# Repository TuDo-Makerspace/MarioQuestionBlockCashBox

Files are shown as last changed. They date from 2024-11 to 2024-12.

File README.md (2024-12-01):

# Mario [ ? ] Block Cash Box <!-- omit in toc -->

https://github.com/user-attachments/assets/13c91ebd-0a8e-42fc-bb54-711a1d9b547c

## Table of Contents <!-- omit in toc -->

- [Building the Box](#building-the-box)
  - [Step 1. Cut the Wood](#step-1-cut-the-wood)
  - [Step 2. Glue the Pieces Together](#step-2-glue-the-pieces-together)
  - [Step 3. Secure the Bottom](#step-3-secure-the-bottom)
  - [Step 4. Lid slit](#step-4-lid-slit)
  - [Step 5. Hole for DC Jack](#step-5-hole-for-dc-jack)
  - [Step 6. Paint the Base Coat](#step-6-paint-the-base-coat)
  - [Step 7. Draw the Pixel Grid](#step-7-draw-the-pixel-grid)
  - [Step 8. Paint the Pixel Art](#step-8-paint-the-pixel-art)
  - [Step 9. Magnets for the Lid](#step-9-magnets-for-the-lid)
- [Electronics](#electronics)
  - [Components Required](#components-required)
  - [Wiring the Components](#wiring-the-components)
- [Software](#software)
  - [Overview](#overview)
  - [Configurable Parameters](#configurable-parameters)
  - [Sound Playback Implementation](#sound-playback-implementation)
- [Flashing the Arduino](#flashing-the-arduino)
- [Electronics Enclosure](#electronics-enclosure)
  - [Enclosure Components](#enclosure-components)
  - [Assembly Instructions](#assembly-instructions)
    - [1. Mounting the Perfboard](#1-mounting-the-perfboard)
    - [2. Attaching Speaker and Sensor](#2-attaching-speaker-and-sensor)
    - [3. Connecting Components](#3-connecting-components)
    - [4. Securing the Enclosure](#4-securing-the-enclosure)
    - [5. Sensor Calibration](#5-sensor-calibration)
    - [6. Screwing on the Lid](#6-screwing-on-the-lid)

## Building the Box

### Step 1. Cut the Wood

For the box, we cut 2 slightly larger pieces (dimensions: X x Y x Z) and 4 slightly smaller pieces (dimensions: X x Y x Z). The larger pieces make up the top and bottom, while the smaller pieces form the sides.

<div align="center">
  Cutting Wood
</div>

### Step 2. Glue the Pieces Together

Once the pieces are cut, glue them together to form the box. Make sure the edges are flush and the corners are square.

<div align="center">
  Gluing
</div>

### Step 3. Secure the Bottom

Attach the bottom of the box using screws or nails for extra stability. Glue alone can work but might not be as durable.

<div align="center">
  Screwing the Bottom
</div>

### Step 4. Lid slit

Cut a slit in the lid to allow coins to be inserted into the box. Make sure the slit is wide enough to accommodate different coin sizes.
We used a size of X x Y.

TODO: Add Image

### Step 5. Hole for DC Jack

Drill a hole into the bottom of any side of the box to make room for a DC jack. We didn't have a panel mount DC jack, so we used a PCB one and simply glued it into the hole. We also soldered a JST connector to the jack so that it can be easily connected to the electronics, while still allowing the other electronics to be removed from the box for maintenance.

### Step 6. Paint the Base Coat

Apply a white base layer of paint to the box. This will make the final colors more vibrant. Acrylic paint is recommended.

<div align="center">
  Base Paint
</div>

### Step 7. Draw the Pixel Grid

Sketch a 16x16 pixel grid on the box. This will serve as a guide for your Super Mario-inspired design.

<div align="center">
  Pixel Grid
</div>

### Step 8. Paint the Pixel Art

Fill in the grid with bright colors to create the iconic Mario Question Block design.

<div align="center">
  Painting Pixels
</div>

### Step 9. Magnets for the Lid

Drill a hole into each corner of the box and lid. Insert and glue magnets into the holes. This allows the lid to remain in place, while still being easy to open.

<div align="center">
  Finished Product
</div>

## Electronics

### Components Required

For the electronics setup, you'll need the following components:

- [Arduino Nano](https://www.amazon.de/s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)
- [PAM8403 Audio Amplifier Board](https://www.amazon.de/DollaTek-5V-Audioverst%C3%A4rker-Digitalendstufenmodul-Stereo-Verst%C3%A4rker-Potentiometer/dp/B07DJWGQVY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)
- [KY-033 Line Tracking Sensor](https://www.amazon.de/KY-033-Anwendbar-Erkennung-Hindernissen-Infrarot-Detektionssensor/dp/B0D3XHR2VL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)
- [Speaker (8- or 4-ohm, rated for 3W or higher)](https://www.amazon.de/s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)

### Wiring the Components

Connect the components as illustrated in the circuit diagram below:

> TODO: Add Circuit Diagram

Circuit Diagram

For our project, we soldered the components onto a perfboard:

> Tip: We utilized JST connectors for connecting the speaker, sensor, and power supply to the perfboard. This allows for better maintainability.

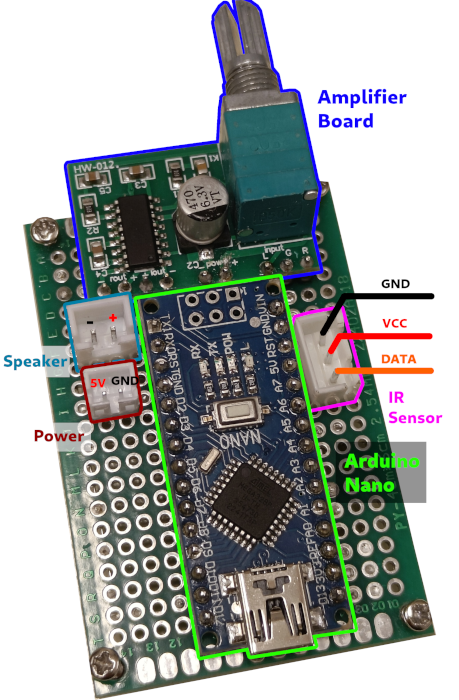
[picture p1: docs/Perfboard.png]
Perfboard


## Software

### Overview

The project's software can be found in the [`src/`](src/) directory. It performs the following actions:

1. Initialization:
   - Initializes GPIO's and serial communication.
   - Displays a playful ASCII art message in the serial monitor.

2. Sensor Monitoring:
   - Continuously monitors input from the KY-033 line tracking sensor.
   - Detects objects (e.g., coins) passing over the sensor by detecting a transition from LOW to HIGH on the sensor pin.

3. Sound Playback:
   Once a coin is detected:
   - Standard: Plays the classic Mario coin sound effect each time a coin is detected.
   - Special: On every *n-th* coin (configurable), it plays either a One-Up or Power-Up sound effect instead of the standard coin sound. Currently, the Power-Up sound is played on every 4th coin and the One-Up sound on every 10th coin.

### Configurable Parameters

At the top of the main file, you can adjust the following parameters:

- `POWER_UP`: Determines the number of coins required to play the Power-Up sound effect.
- `ONE_UP`: Determines the number of coins required to play the One-Up sound effect.
- `SENSOR_PIN`: Specifies the pin connected to the KY-033 sensor.
- `WAIT_AFTER_COIN`: Sets the waiting time between consecutive sound playbacks. This prevents spam if the coin is detected for a longer duration.

### Sound Playback Implementation

We utilize [Damellis's PCM Library](https://github.com/damellis/PCM) to handle audio playback. To play a sound, we can use the startPlayback() function, which takes an array of raw 8-bit audio values. The Mario audio samples are stored in the `sounds.h` file as byte arrays, however, due to copyright restrictions, `sounds.h` is not included in this repository. Makerspace Members can access the file on our file server. For others, refer to this [Tutorial](https://highlowtech.org/?p=1963) for instructions.

## Flashing the Arduino

To upload the software to your Arduino Nano, follow these steps:

1. Install PlatformIO:
   - Download and install [PlatformIO](https://platformio.org/) as an extension for your preferred IDE (e.g., VS Code).

2. Open the Project:
   - Launch PlatformIO and open this project by navigating to `File > Open Folder` and selecting the project's root directory.

3. Connect Your Arduino:
   - Use a USB cable to connect your Arduino Nano to your computer.

4. Upload the Firmware:
   - In PlatformIO, click the Upload button (usually represented by an arrow icon) to compile and flash the software to your Arduino.

## Electronics Enclosure

To securely house the electronics and ensure proper protection, we designed and 3D printed a custom enclosure tailored specifically to our components (i.e. our Speaker, Perfboard etc.). Provided that you likely have different components, you will need to come up with your own enclosure design. **This section mostly serves as a reference for members of our makerspace to repair or modify our coin box.**

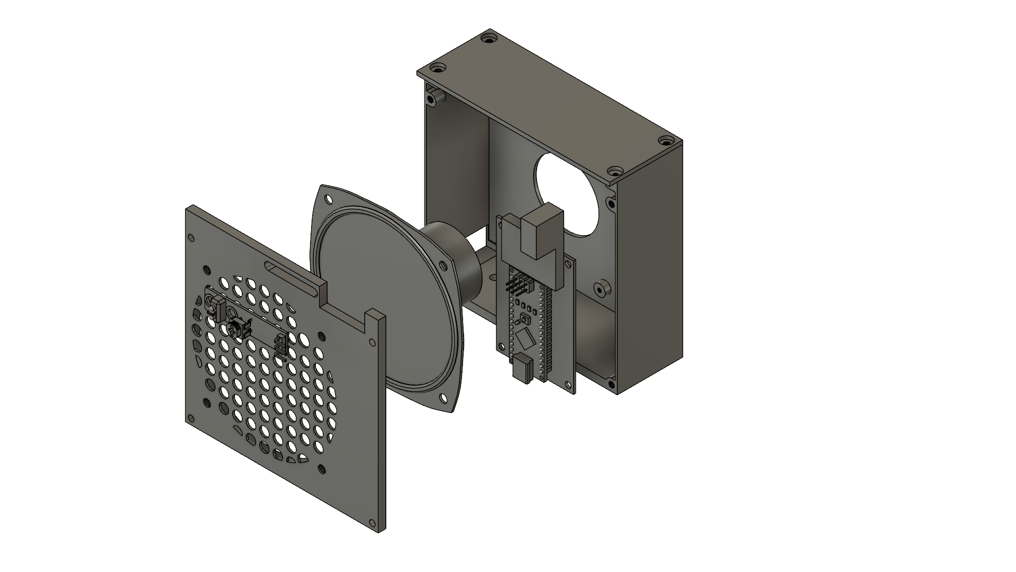
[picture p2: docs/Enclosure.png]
Enclosure


### Enclosure Components

The enclosure consists of three main parts. Click on the links below to download the corresponding `.3mf` files:

- [Back Part](enclosure/Back.3mf): Holds the perfboard containing the Arduino Nano and the Audio Amplifier.
- [Front Part](enclosure/Front.3mf): Houses the speaker and the sensor.
- [Lid](enclosure/Lid.3mf): Covers the enclosure once the front and back parts are assembled.

### Assembly Instructions

#### 1. Mounting the Perfboard

Secure the perfboard onto the Back Part of the enclosure using M2 screws.

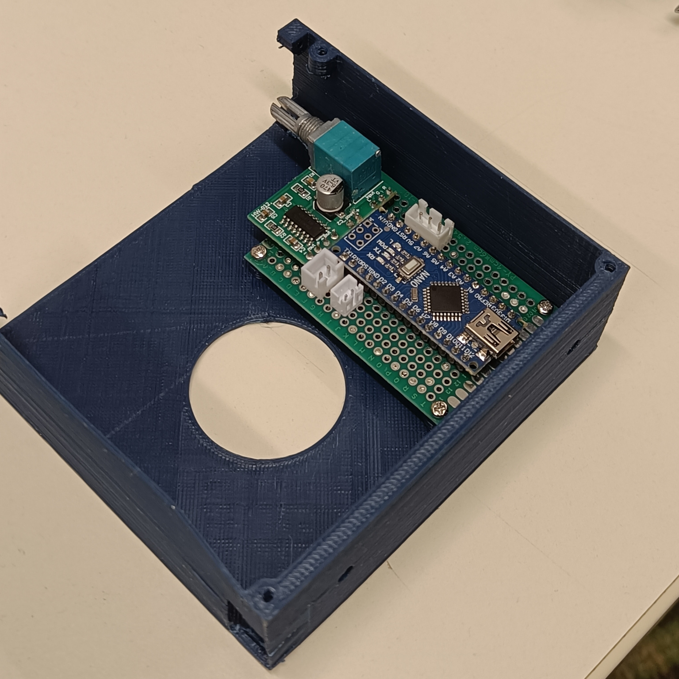
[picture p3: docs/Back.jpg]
Back Part
   

#### 2. Attaching Speaker and Sensor

Attach the speaker and KY-033 sensor to the Front Part of the enclosure using M3 screws and a nut.

> Note: Do not fully tighten the nut for the sensor yet, as you may need to adjust its position later.
   
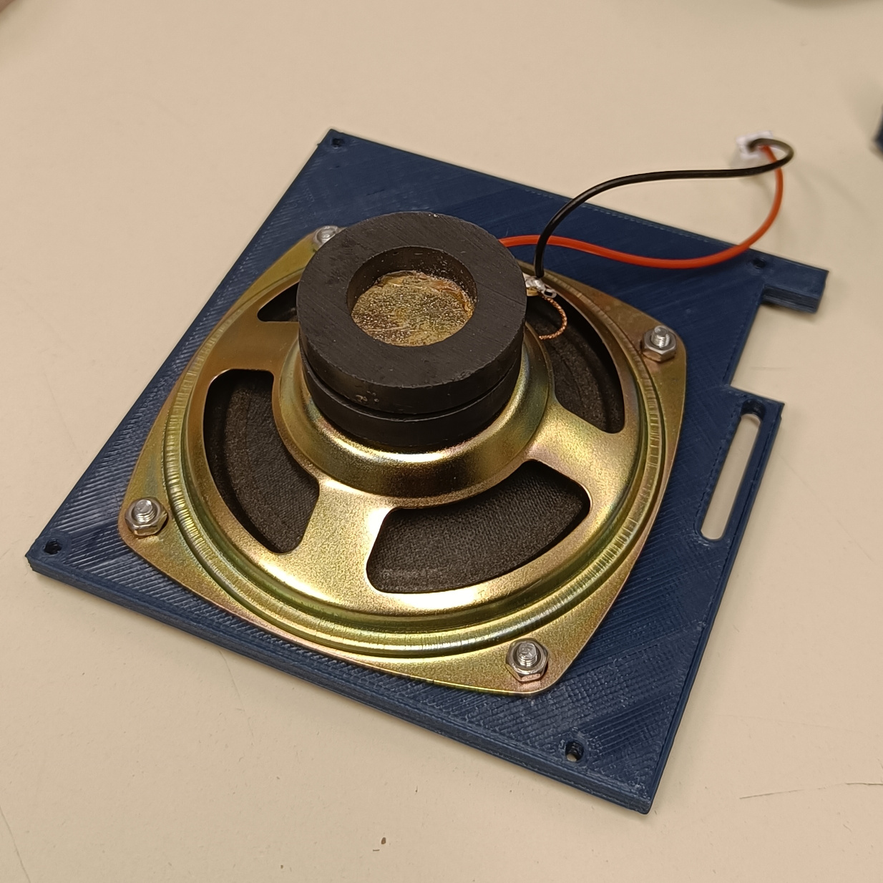
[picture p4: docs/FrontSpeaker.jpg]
Front Part
   
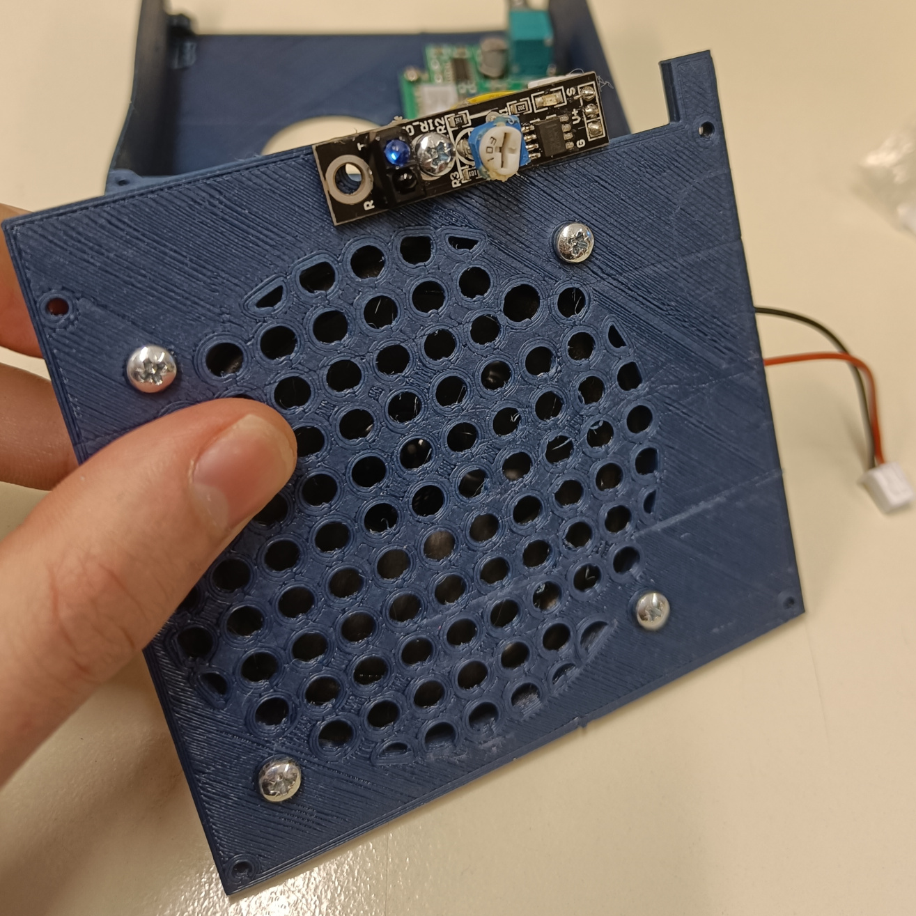
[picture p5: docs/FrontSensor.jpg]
Front Part
   

#### 3. Connecting Components

Connect the sensor, speaker, and DC barrel jack to the perfboard.

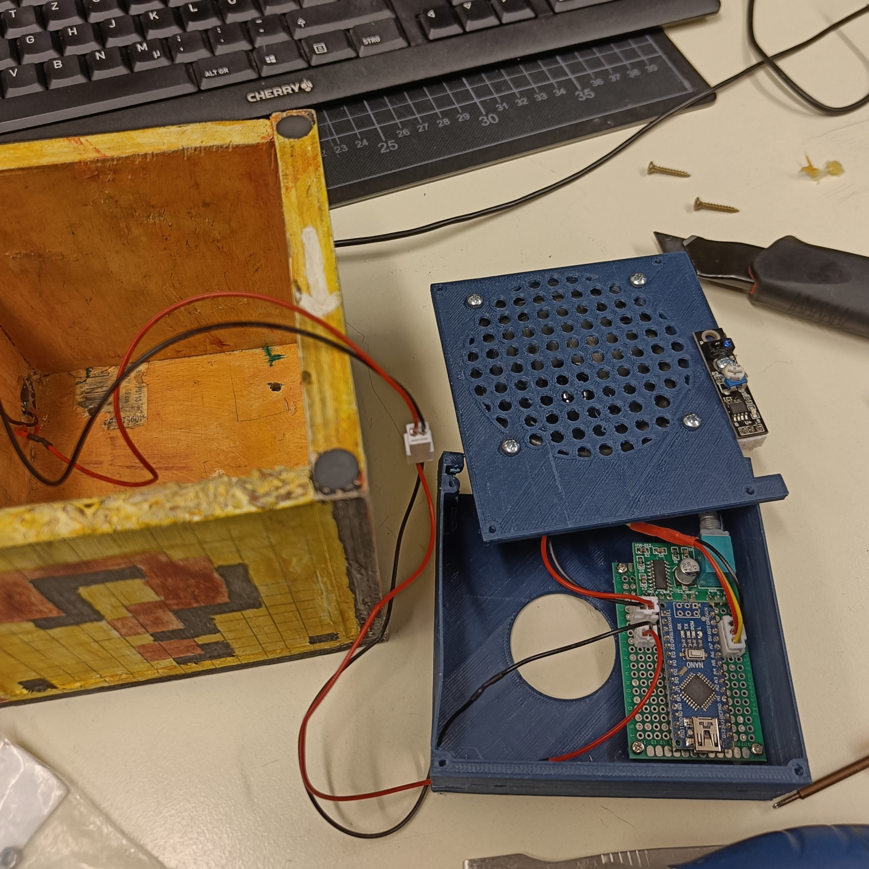
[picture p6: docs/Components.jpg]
Components


#### 4. Securing the Enclosure

Screw the front and back parts together using M3 screws. Then insert the assembled electronics into the wooden box. This may require some force. Use two wooden screws from the bottom of the wooden box to secure the enclosure in place through the designated holes.

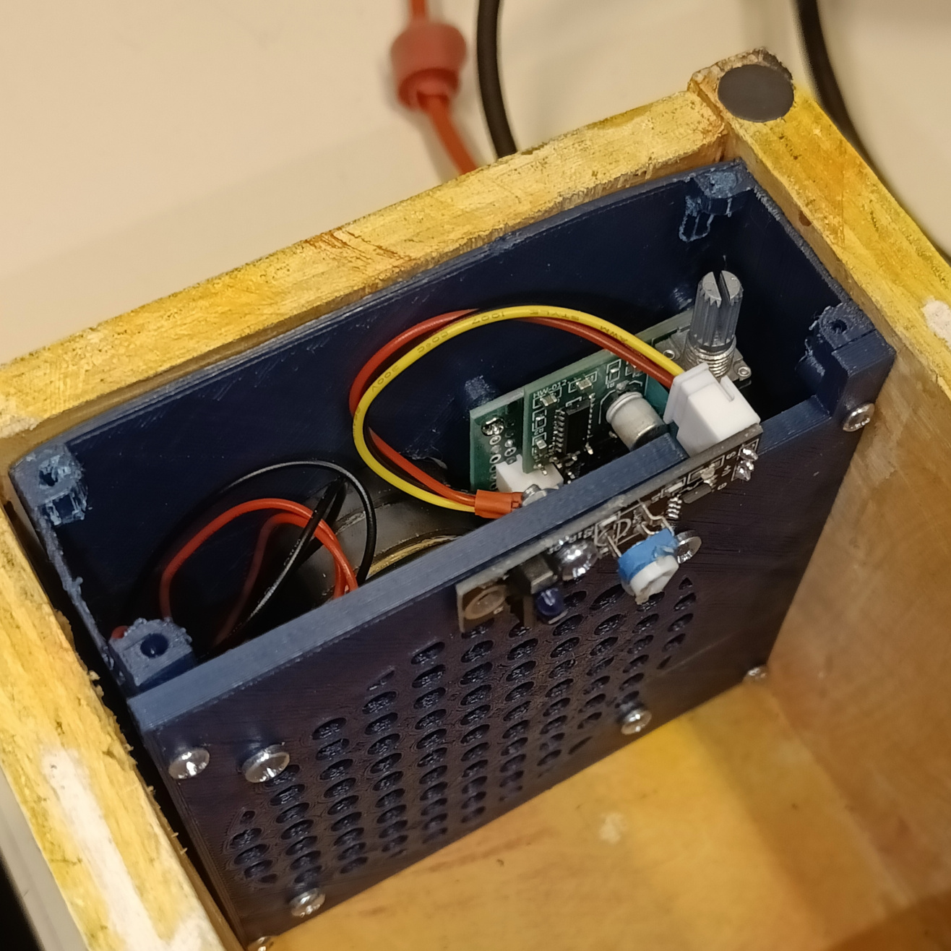
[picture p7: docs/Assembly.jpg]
Assembled

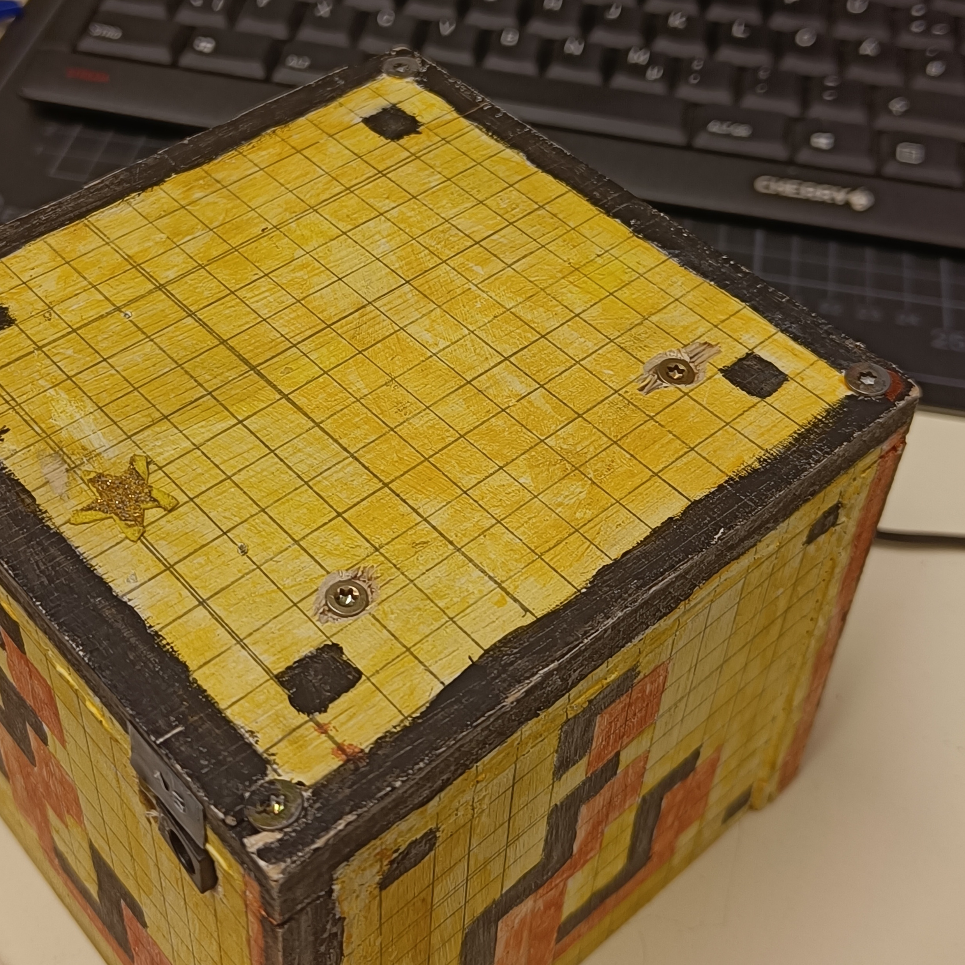
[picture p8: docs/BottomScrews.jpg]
Bottom Screws


#### 5. Sensor Calibration

- Before attaching the lid, power up the electronics and calibrate the sensor sensitivity to detect coins.
- Place the box lid on top of the enclosure.
- Test the sensor by inserting small coins. If the sensor misses any coins, adjust its position by loosening the nut, repositioning the sensor, and then tightening the nut once satisfied.

#### 6. Screwing on the Lid

Once the sensor is properly positioned, secure the 3D printed lid onto the enclosure using three M3 screws and one M2 screw.

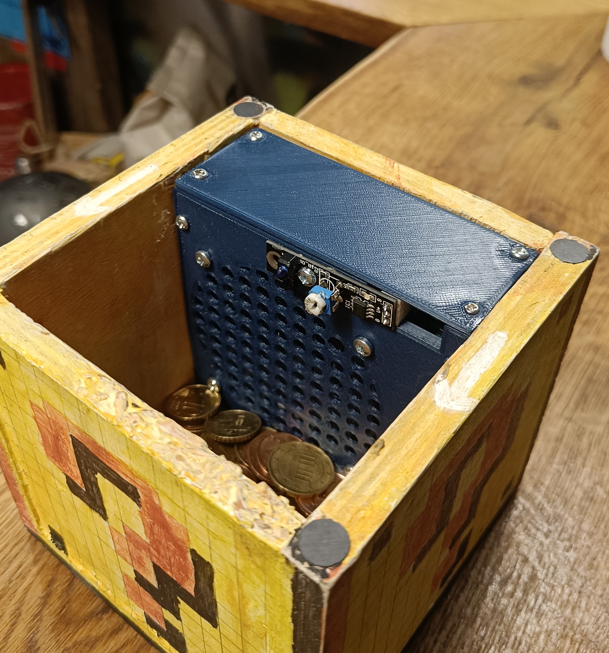
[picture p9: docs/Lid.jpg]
Lid


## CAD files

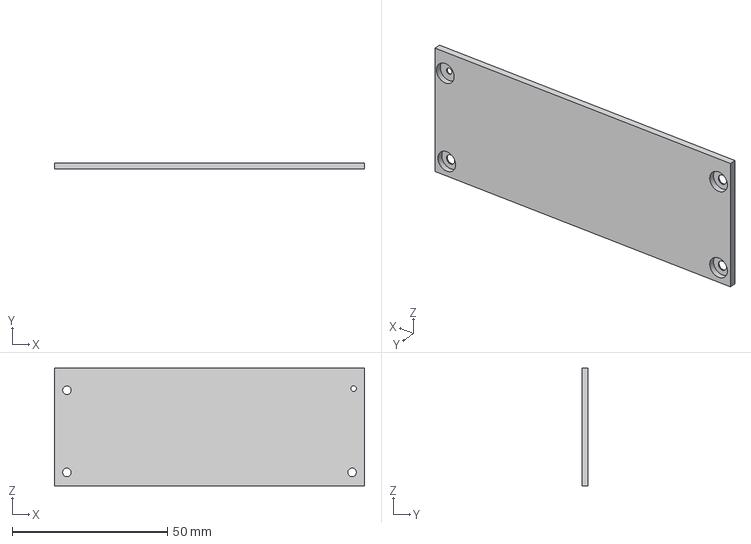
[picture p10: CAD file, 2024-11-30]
enclosure/Lid.3mf
100.0 x 2.00 x 38.0 mm

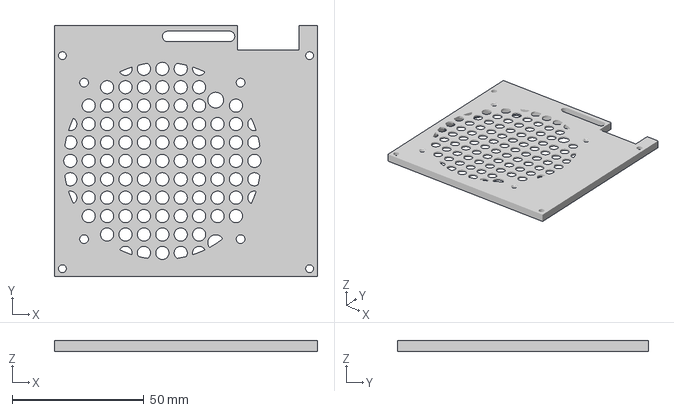
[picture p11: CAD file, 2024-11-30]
enclosure/Front.3mf
100.0 x 95.5 x 4.00 mm

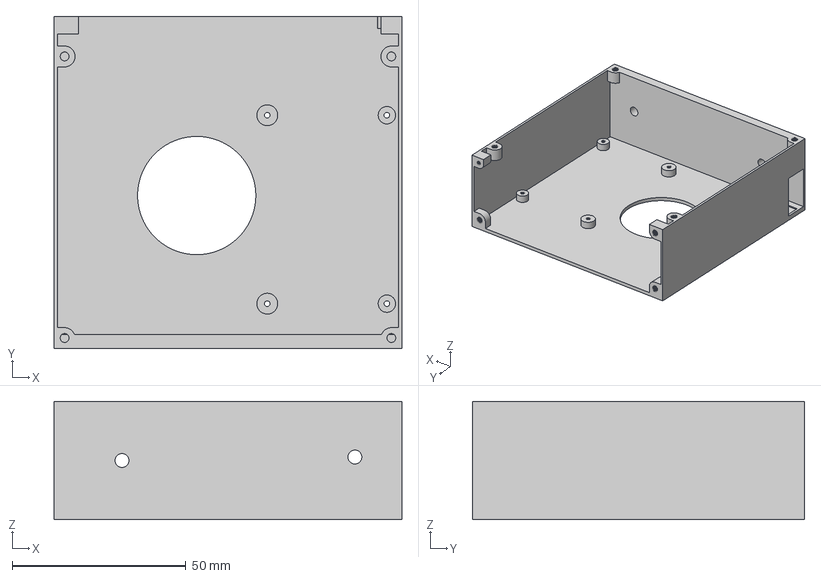
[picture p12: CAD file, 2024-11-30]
enclosure/Back.3mf
100.0 x 95.5 x 34.0 mm

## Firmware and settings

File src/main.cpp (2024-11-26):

/*
 * main.cpp
 *
 * Author       : Yunis, Patrick Pedersen
 * Description  : Main code for the coin box
 *
 */

#include <Arduino.h>
#include <PCM.h>

#include "sounds.h"

//// Parameters

// Pins
// Sound is on pin 11
#define SENSOR_PIN A7

// Number of coins to trigger sound
#define POWER_UP 4
#define ONE_UP 10

// Function
#define WAIT_AFTER_COIN 100 // ms

/* From: https://docs.arduino.cc/language-reference/en/functions/digital-io/digitalread/:
 *   The analog input pins can be used as digital pins, referred to as A0, A1, etc.
 *   The exception is the Arduino Nano, Arduino Pro Mini, and Arduino Mini’s A6 and A7 pins,
 *   which can only be used as analog inputs. */
#if SENSOR_PIN == A6 || SENSOR_PIN == A7
    #define SENSOR_THRESHOLD 512
    #define SENSOR_READ() (analogRead(SENSOR_PIN) > SENSOR_THRESHOLD ? HIGH : LOW)
#else
    #define SENSOR_READ() digitalRead(SENSOR_PIN)
#endif

void print_boot_msg() {
  Serial.println("@@@@/////////////////////////////////////////////////@@@@\n");
  Serial.println("////,,,,,,,,,,,,,,,,,,,,,,,,,,,,,,,,,,,,,,,,,,,,,,,,,@@@@\n");
  Serial.println("////,,,,,,,,,,,,,,,,,,,,,,,,,,,,,,,,,,,,,,,,,,,,,,,,,@@@@\n");
  Serial.println("////,,,@@@@,,,,,,,,,,,,,,,,,,,,,,,,,,,,,,,,,,,@@@@,,,@@@@\n");
  Serial.println("////,,,,,,,,,,,,,,/////////////////*,,,,,,,,,,,,,,,,,@@@@\n");
  Serial.println("////,,,,,,,,,,,,,,/////////////////*,,,,,,,,,,,,,,,,,@@@@\n");
  Serial.println("////,,,,,,,,,,///////@@@@@@@@@@@///////,,,,,,,,,,,,,,@@@@\n");
  Serial.println("////,,,,,,,,,,///////@@@@,,,,,,,///////@@@@,,,,,,,,,,@@@@\n");
  Serial.println("////,,,,,,,,,,///////@@@@,,,,,,,///////@@@@,,,,,,,,,,@@@@\n");
  Serial.println("////,,,,,,,,,,///////@@@@,,,,,,,///////@@@@,,,,,,,,,,@@@@\n");
  Serial.println("////,,,,,,,,,,,,,,@@@@@@@,,,///////////@@@@,,,,,,,,,,@@@@\n");
  Serial.println("////,,,,,,,,,,,,,,,,,,,,,///////@@@@@@@@@@@,,,,,,,,,,@@@@\n");
  Serial.println("////,,,,,,,,,,,,,,,,,,,,,///////@@@@@@@@@@@,,,,,,,,,,@@@@\n");
  Serial.println("////,,,,,,,,,,,,,,,,,,,,,///////@@@#,,,,,,,,,,,,,,,,,@@@@\n");
  Serial.println("////,,,,,,,,,,,,,,,,,,,,,,,,@@@@@@@#,,,,,,,,,,,,,,,,,@@@@\n");
  Serial.println("////,,,,,,,,,,,,,,,,,,,,,///////,,,,,,,,,,,,,,,,,,,,,@@@@\n");
  Serial.println("////,,,,,,,,,,,,,,,,,,,,,///////,,,,,,,,,,,,,,,,,,,,,@@@@\n");
  Serial.println("////,,,,,,,,,,,,,,,,,,,,,///////@@@#,,,,,,,,,,,,,,,,,@@@@\n");
  Serial.println("////,,,@@@@,,,,,,,,,,,,,,,,,@@@@@@@#,,,,,,,,,,@@@@,,,@@@@\n");
  Serial.println("////,,,@@@@,,,,,,,,,,,,,,,,,@@@@@@@#,,,,,,,,,,@@@@,,,@@@@\n");
  Serial.println("////,,,,,,,,,,,,,,,,,,,,,,,,,,,,,,,,,,,,,,,,,,,,,,,,,@@@@\n");
  Serial.println("@@@@@@@@@@@@@@@@@@@@@@@@@@@@@@@@@@@@@@@@@@@@@@@@@@@@@@@@@\n");
  Serial.println("\n\n");
  Serial.println("Mario Coin box by Yunis! ft. Patrick :) !!!!11!\n");
}

int money = 1;

void setup() {
  pinMode(SENSOR_PIN, INPUT);
  Serial.begin(9600);
  print_boot_msg();
}

void loop() {
  static uint8_t last_val = SENSOR_READ();
  uint8_t val = SENSOR_READ();

  if (last_val == LOW && val == HIGH) {

    Serial.print("Coin detected! Playing: ");

    if ((money % POWER_UP) == 0) {
      Serial.println("Power up!");
      startPlayback(powerup, sizeof(powerup));
    } else if ((money % ONE_UP) == 0) {
      Serial.println("One up!");
      startPlayback(oneup, sizeof(oneup));
    } else {
      Serial.println("Coin sound!");
      startPlayback(coin, sizeof(coin));
    }
    money++;

    delay(WAIT_AFTER_COIN);
  }

  last_val = val;
}

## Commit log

2024-11-26 Updated to work with new board
2024-11-26 Use analogRead for A6/A7 only
    From https://docs.arduino.cc/language-reference/en/functions/digital-io/digitalread/:
    The analog input pins can be used as digital pins, referred to as A0, A1, etc. The exception is the Arduino Nano, Arduino Pro Mini, and Arduino Mini’s A6 and A7 pins, which can only be used as analog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
